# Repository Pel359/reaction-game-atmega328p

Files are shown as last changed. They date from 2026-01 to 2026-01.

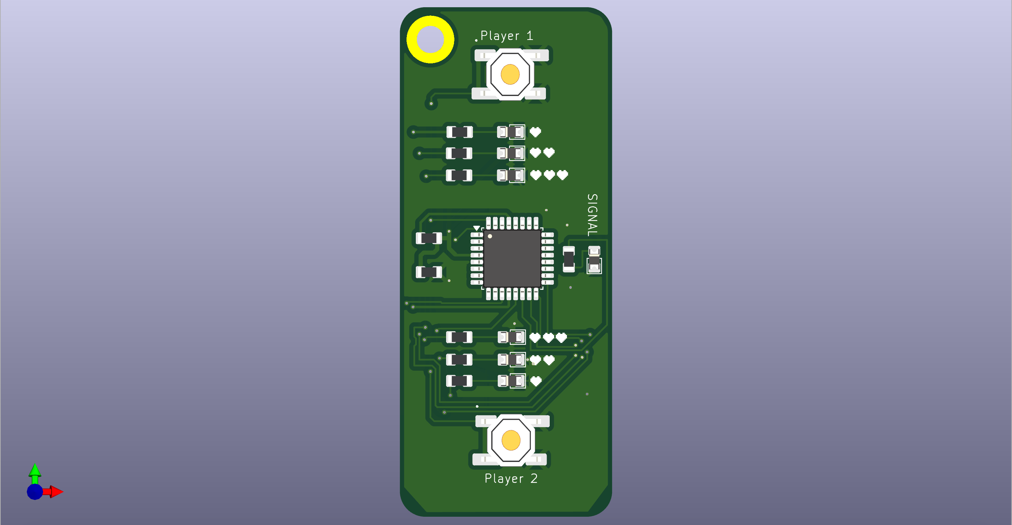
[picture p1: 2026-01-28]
images/v2/3D.png

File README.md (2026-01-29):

# Игра на реакцию для двух игроков на ATmega328P

DIY-гаджет: игра на реакцию для двух игроков. После случайной задержки загорается центральный зелёный светодиод — кто быстрее нажмёт свою кнопку, тот выигрывает раунд. Первый до 3 очков выигрывает матч.

Проект на "голом" ATmega328P (без Arduino-платы). Код написан в Arduino IDE (только core-функции, без библиотек), прошивка HEX-файлом через программатор (T48).

## Оглавление
- [Версии](#версии)
- [Механика игры](#механика-игры)
- [Список компонентов (BOM)](#список-компонентов-bom)
- [Сборка и прошивка](#сборка-и-прошивка)
- [Код](#код)

## Версии
- **v1.0** : простая индикация — LED1 (P1) и  LED2 (P2) мигают при победе в раунде. При победе в матче — быстрое мигание индикатора победителя.
  Плата сверху
- **v2.0** (в разработке): улучшенная индикация — по три LED на игрока . Индикаторы счёта зажигаются последовательно и остаются гореть. При победе в матче — красивая поочерёдная анимация всех трёх индикаторов победителя.

## Механика игры (общая для обеих версий)
- Стартовый сигнал: 3 коротких моргания центрального  LED.
- Случайная задержка 1–5 секунд.
- Анти-чит: более 2 нажатий кнопки во время ожидания — игрок блокируется на раунд.
- После загорания центрального LED — 5 секунд на реакцию.
- Матч до 3 очков.
- Автоматический сброс после окончания матча.

## Список компонентов (BOM)

| Компонент | Кол-во (v1.0) | Кол-во (v2.0) | Примечание |
|---|---|---|---|
| ATmega328P | 1 | 1 | |
| Тактовые кнопки 6×6 мм | 2 | 2 | |
| Светодиод smd (0805) | 1 | 1 | Центральный |
| Светодиод smd (0805) | 1 | 3 | P1 |
| Светодиод smd (0805) | 1 | 3 | P2 |
| Резисторы | 3 | 7 | Для LED 330 Ом |
| Резисторы | 1 | 1 | 10 кОм |
| Батарейный отсек CR2032 | 1 | 1 | |
| Конденсатор | 1 | 1 | 1мКф | 

## Код

- v1.0: `/src/v1/reaction_game_v1.ino`
- v2.0: `/src/v2/reaction_game_v2.ino`
- HEX-файлы: `/firmware/`

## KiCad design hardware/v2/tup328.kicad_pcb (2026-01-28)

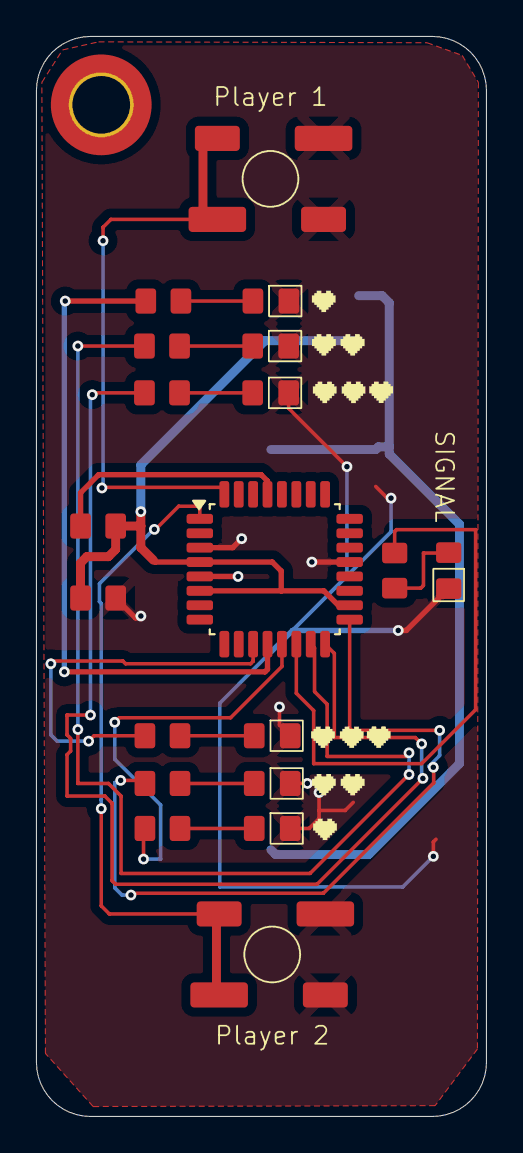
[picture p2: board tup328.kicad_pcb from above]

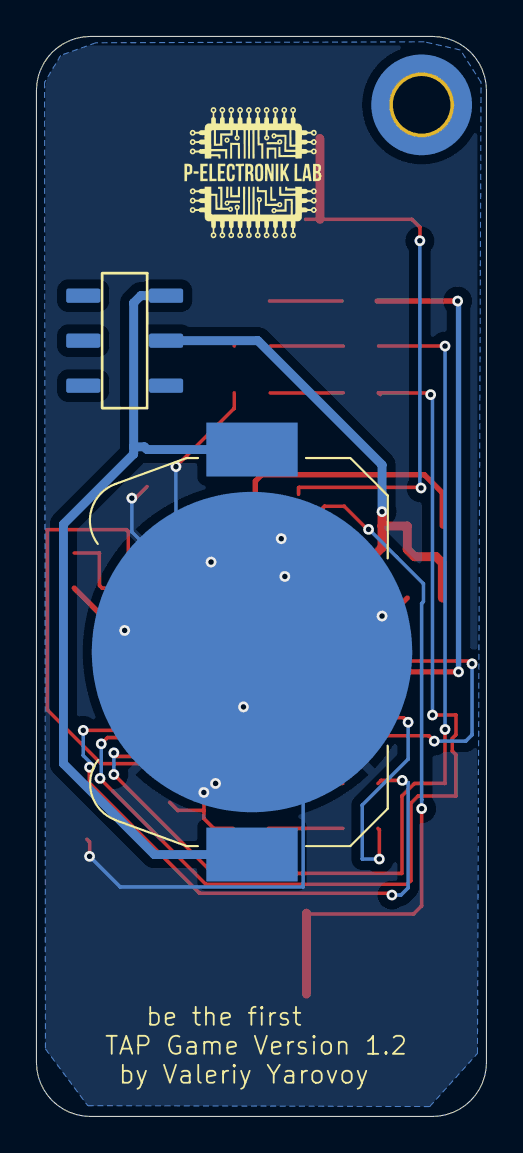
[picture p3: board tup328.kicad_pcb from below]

Board: 2 copper layers, 25.0 x 60.0 mm, 22 parts (2 on the bottom side), 20 nets.

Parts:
BT1: Battery_Cell; tupBatteryHolder_Keystone_3034_1x20mm
C1: 1uF; 0805_Capacitor_prodject_version1_copy
D1, D2, D4, D5, D6, D7: 0805_LED_prodject_version1
H1: MountingHole; MountingHole_3.2mm_M3_DIN965_Pad_TopBottom
Player 1 , Player 2: SW_MEC_5E; SWITCH_6x6_Led_peoject
R1, R2, R3, R4, R5, R6, R7, R8: R; 0805_Capacitor_prodject_version1_copy
SIGNAL: 0805_LED_prodject_version1
SW3: SW_DPDT_x2; Knopka 1
U1: ATmega328P-A; TQFP-32_7x7mm_P0.8mm

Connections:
GND: BT1.2 (-), C1.2, D1.2 (K), D2.2 (K), D4.2 (K), D5.2 (K), D6.2 (K), D7.2 (K), Player 1.3 (K), Player 1.4 (A), Player 2.3 (K), Player 2.4 (A), SIGNAL.2 (K), U1.3 (GND), U1.5 (GND), U1.21 (GND)
unnamed: BT1.1 (+), SW3.1 (A)
unnamed: D1.1 (A), R1.2
unnamed: D2.1 (A), R2.2
unnamed: R3.2, SIGNAL.1 (A)
unnamed: D4.1 (A), R5.2
unnamed: D5.1 (A), R6.2
unnamed: D6.1 (A), R7.2
unnamed: D7.1 (A), R8.2
unnamed: R1.1, U1.12 (PB0)
unnamed: R2.1, U1.13 (PB1)
unnamed: R3.1, U1.14 (PB2)
unnamed: R5.1, U1.15 (PB3)
unnamed: R6.1, U1.16 (PB4)
unnamed: R7.1, U1.17 (PB5)
unnamed: Player 1.1, Player 1.2, U1.32 (PD2)
unnamed: Player 2.1, Player 2.2, U1.1 (PD3)
unnamed: R8.1, U1.11 (PD7)
unnamed: R4.1, U1.29 (~RESET/PC6)
VCC: C1.1, R4.2, SW3.2 (B), U1.4 (VCC), U1.6 (VCC), U1.18 (AVCC)

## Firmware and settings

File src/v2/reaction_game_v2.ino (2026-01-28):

#include <Arduino.h>

#define LED1_1 8   // Первый индикатор  P1 (PB0)
#define LED1_2 11  // Второй индикатор  P1 (PB3)
#define LED1_3 12  // Третий индикатор  P1 (PB4)
#define LED2   10  // Центр (PB2)
#define LED2_1 9   // Первый индикатор  P2 (PB1)
#define LED2_2 13  // Второй индикатор  P2 (PB5)
#define LED2_3 7   // Третий индикатор  P2 (PD7)
#define BUTTON1 2  // Кнопка P1
#define BUTTON2 3  // Кнопка P2

int scoreP1 = 0;
int scoreP2 = 0;

// Обновляем индикаторы счёта
void updateScoreLEDsP1() {
  digitalWrite(LED1_1, scoreP1 >= 1 ? HIGH : LOW);
  digitalWrite(LED1_2, scoreP1 >= 2 ? HIGH : LOW);
  digitalWrite(LED1_3, scoreP1 >= 3 ? HIGH : LOW);
}

void updateScoreLEDsP2() {
  digitalWrite(LED2_1, scoreP2 >= 1 ? HIGH : LOW);
  digitalWrite(LED2_2, scoreP2 >= 2 ? HIGH : LOW);
  digitalWrite(LED2_3, scoreP2 >= 3 ? HIGH : LOW);
}

// Анимация победы в матче (поочерёдное мигание всех трёх индикаторов 5 раз)
void victoryAnimationP1() {
  for (int i = 0; i < 5; i++) {
    digitalWrite(LED1_1, HIGH); delay(200); digitalWrite(LED1_1, LOW);
    digitalWrite(LED1_2, HIGH); delay(200); digitalWrite(LED1_2, LOW);
    digitalWrite(LED1_3, HIGH); delay(200); digitalWrite(LED1_3, LOW);
  }
}

void victoryAnimationP2() {
  for (int i = 0; i < 5; i++) {
    digitalWrite(LED2_1, HIGH); delay(200); digitalWrite(LED2_1, LOW);
    digitalWrite(LED2_2, HIGH); delay(200); digitalWrite(LED2_2, LOW);
    digitalWrite(LED2_3, HIGH); delay(200); digitalWrite(LED2_3, LOW);
  }
}

void normalRound() {
  // Рандомная задержка перед стартом
  unsigned long waitDuration = random(1000, 5001);
  unsigned long waitStart = millis();

  int cheatCountP1 = 0;
  int cheatCountP2 = 0;
  bool blockedP1 = false;
  bool blockedP2 = false;

  byte prevStateB1 = HIGH;
  byte prevStateB2 = HIGH;

  // Фаза ожидания (анти-спам)
  while (millis() - waitStart < waitDuration) {
    byte currentB1 = digitalRead(BUTTON1);
    if (currentB1 == LOW && prevStateB1 == HIGH) {
      cheatCountP1++;
      if (cheatCountP1 > 2) blockedP1 = true;
      while (digitalRead(BUTTON1) == LOW);
      delay(20);
    }
    prevStateB1 = currentB1;

    byte currentB2 = digitalRead(BUTTON2);
    if (currentB2 == LOW && prevStateB2 == HIGH) {
      cheatCountP2++;
      if (cheatCountP2 > 2) blockedP2 = true;
      while (digitalRead(BUTTON2) == LOW);
      delay(20);
    }
    prevStateB2 = currentB2;
  }

  // Старт раунда — зажигаем центр
  digitalWrite(LED2, HIGH);

  unsigned long reactionStart = millis();
  bool pressed = false;

  // Фаза реакции
  while (millis() - reactionStart < 5000 && !pressed) {
    if (!blockedP1 && digitalRead(BUTTON1) == LOW) {
      scoreP1++;
      updateScoreLEDsP1();   // Зажигаем следующий индикатор (и он остаётся гореть)
      digitalWrite(LED2, LOW);
      pressed = true;
    } else if (!blockedP2 && digitalRead(BUTTON2) == LOW) {
      scoreP2++;
      updateScoreLEDsP2();   // Зажигаем следующий индикатор (и он остаётся гореть)
      digitalWrite(LED2, LOW);
      pressed = true;
    }
  }

  if (!pressed) {
    digitalWrite(LED2, LOW);  
  }
}

void setup() {
  pinMode(LED1_1, OUTPUT);
  pinMode(LED1_2, OUTPUT);
  pinMode(LED1_3, OUTPUT);
  pinMode(LED2, OUTPUT);
  pinMode(LED2_1, OUTPUT);
  pinMode(LED2_2, OUTPUT);
  pinMode(LED2_3, OUTPUT);
  pinMode(BUTTON1, INPUT_PULLUP);
  pinMode(BUTTON2, INPUT_PULLUP);

  randomSeed(analogRead(A0));

  // Стартовый сигнал: 3 моргания центра
  for (int i = 0; i < 3; i++) {
    digitalWrite(LED2, HIGH);
    delay(500);
    digitalWrite(LED2, LOW);
    delay(500);
  }

  // На старте счёт 0 — все индикаторы погашены
  updateScoreLEDsP1();
  updateScoreLEDsP2();
}

void loop() {
  // Перед каждым раундом обновляем индикаторы (чтобы они продолжали гореть)
  updateScoreLEDsP1();
  updateScoreLEDsP2();
  digitalWrite(LED2, LOW);  

  normalRound();
// Проверка победы в матче (до 3 очков)
  if (scoreP1 >= 3) {
    victoryAnimationP1();  // Анимация победы
    scoreP1 = 0;
    scoreP2 = 0;
    // Гасим все индикаторы для нового матча
    digitalWrite(LED1_1, LOW);
    digitalWrite(LED1_2, LOW);
    digitalWrite(LED1_3, LOW);
    digitalWrite(LED2_1, LOW);
    digitalWrite(LED2_2, LOW);
    digitalWrite(LED2_3, LOW);
    delay(2000);
  } else if (scoreP2 >= 3) {
    victoryAnimationP2();
    scoreP1 = 0;
    scoreP2 = 0;
    digitalWrite(LED1_1, LOW);
    digitalWrite(LED1_2, LOW);
    digitalWrite(LED1_3, LOW);
    digitalWrite(LED2_1, LOW);
    digitalWrite(LED2_2, LOW);
    digitalWrite(LED2_3, LOW);
    delay(2000);
  }

  delay(1000);  // Пауза перед следующим раундом
}

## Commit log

2026-01-28 Add photos for assembled v1.0 board
2026-01-28 Add photos for assembled v2.0 board
2026-01-28 Rename 2026-01-28_20-20-10.png to PCB 1.png
2026-01-28 Rename 2026-01-28_20-17-12.png to PCB 2.png
2026-01-28 Add KiCad project files for v1.0
    [tupvs1.kicad_pcb]
2026-01-28 Add KiCad project files for v2.0
    [tup328.kicad_pcb]
2026-01-28 Add Gerber files for v1.0 and v2.0 manufacturing
